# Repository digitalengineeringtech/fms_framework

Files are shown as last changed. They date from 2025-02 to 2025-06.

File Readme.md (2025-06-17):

# FMS Firmware

Fuel Station Monitoring System

## Table of Contents

- [Flow](#flow)
- [VS Code Extension](#vs-code-extension)
- [Compiling Tests](#compiling-tests)
- [Usage/Examples](#usageexamples)
- [Roadmap](#roadmap)
- [Documentation](#documentation)
- [Requirement](#requirement)
- [Skills](#skills)
- [Badges](#badges)

<!-- ## Flow
1. board number
2. crc 
3.  -->
<!-- ![App Screenshot](https://github.com/digitalengineeringtech/fms_framework/blob/main/Flow.jpg) -->

## VS Code Extension

To run this project, you will need to add the following extension variables to your VS Code:

- `Arduino Community Edition`
- `vscode-arduino`

## Compiling Tests

To compile tests, run the following commands:

```bash
ctrl+alt+r   # Compiling sketch
ctrl+alt+u   # Uploading sketch to FMS controller board
```

## Usage/Examples

```c++
#include <fms_header.h>

void setup() {
    fms_log_printf("Program Starting");
    fms_task_create();
}

int strcasecmp(const char *str1, const char *str2);

#include <stdio.h>
#include <strings.h>  // Required for strcasecmp

int main() {
    char str1[] = "Hello";
    char str2[] = "hello";
    
    if (strcasecmp(str1, str2) == 0) {
        printf("Strings are equal (case-insensitive)\n");
    } else {
        printf("Strings are NOT equal\n");
    }
    
    return 0;
}
```

## Roadmap

- All Fuel Protocol Support
- Add more integrations

## Documentation

[Documentation](https://github.com/digitalengineeringtech/fms_framework/blob/main/FMS_FW_Architecture_P2.0.adoc)

## Requirement

[API](https://github.com/digitalengineeringtech/fms_framework/blob/main/whatdo.md)

## Skills

Arduino, FreeRTOS, C++, MQTT, HTML, CSS

## Badges





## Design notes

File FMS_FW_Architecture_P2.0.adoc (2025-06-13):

= Software Architecture for Pump Station with Multiplexer and RS485 Support
:sectnums:
:toc:

[.text-center]
**Company Name**: DET  
[.text-center]
**Engineer Name**: Thiha Kyaw  
[.text-center]
**Document Version**: P2.0  
[.text-center]
**Release Date**: 22-01-2025  

== Version Control Table

[cols="1,3,2,2,3", options="header"]
|===
| Version | Description of Changes | Author | Date | Approval
| P1.0 | Initial version | Thiha Kyaw | 22-01-2025 | Approved by Senior Engineer
| P2.0 | Updated version with multiplexer and RS485 support for pump stations | Thiha Kyaw | 22-01-2025 | Approved by Senior Engineer
| P2.0.1 | Add Cli Command | Nyein Chan Ko | 1-02-2025 | Approved by Senior Engineer
| P2.0.2 | Fix Log Print  | Nyein Chan Ko | 3-03-2025 | Approved by 
| P2.0.3 | Add OTA with Admin | Nyein Chan Ko | 10-03-2025 | Approved by 
| P2.0.4 | Add SD Test | Nyein Chan Ko | 10-03-2025 | Approved by 
| P2.0.5 | Add Modubs Lanfeng | Nyein Chan Ko | 17-03-2025 | Approved by 
| P2.0.6 | Fix Lanfeng Protocol | Nyein Chan Ko | 4-04-2025 | Approved by 
| P2.0.7 | Add Tatsuno | Nyein Chan Ko | 1-06-2025 | Approved by
|===

== Background

This document provides the detailed software architecture for a system designed to acquire data from multiple pumps in a pump station. The system uses an Arduino-based ESP32 microcontroller to communicate with pumps via either RS485 or a hardware multiplexer connected to UART2. Data collected from pumps, such as price, total liters dispensed, and other critical metrics, is transmitted to a remote MQTT server. If the server is unavailable, the data along with error codes are logged into the SDCard and synchronized with the server when communication is restored.

The architecture supports device configuration through a command-line interface (CLI) over UART1 and a user-friendly local web server. Critical device settings, including pump IDs, WiFi credentials, and server configurations, are stored persistently in the SDCard and loaded during device boot-up.

== Requirements

=== Must-Have
1. The system must read data from pumps using UART2 through either RS485 or a hardware multiplexer.
2. The system must provide a CLI for configuration via UART1.
3. The system must host a local web server for device configuration.
4. Configuration settings such as device IDs, WiFi credentials, and pump information must be stored in the SDCard and loaded at boot-up.
5. Data from pumps must be sent to an MQTT server in real time.
6. When the server is unavailable, data and error codes must be logged into the SDCard.
7. Logged data must be synchronized with the server when communication is restored.

=== Should-Have
1. The web server should have password protection for security.
2. The system should support secure MQTT communication (e.g., TLS/SSL).

=== Could-Have
1. The system could store additional logs for detailed troubleshooting.
2. The system could support over-the-air (OTA) firmware updates.

=== Won’t-Have
1. Advanced protocols like Modbus or CAN will not be included in the initial release.
2. High-speed analytics or streaming capabilities will not be implemented on the device.

== Method

=== System Overview
The system is designed with the following key components:
- **Arduino-based Microcontroller**: Manages communication and processing.
- **Hardware Multiplexer** or **RS485**: Allows communication with pumps through UART2.
- **SDCard**: Stores persistent configuration data, logs data when the server is unavailable, and error codes.
- **MQTT Communication**: Sends pump data to the server.
- **Web Server and CLI**: Provide configuration interfaces.

=== Device Configuration Parameters
- **Device ID**: Unique identifier for the device.
- **Station ID**: Identifier for the pump station.
- **WiFi SSID/Password**: WiFi network credentials.
- **MQTT Server IP/Port**: Server details for data transmission.
- **Pump Count/IDs**: Details of connected pumps.
- **Multiplexer Control Pins**: GPIO pin configuration for pump communication (if using Multiplexer).
- **RS485 Configuration**: Communication settings for RS485 (if used).
- **Debug Flags**: Enable/disable debugging.
- **Boot Counter**: Tracks device reboots.

=== Communication Modules
- **UART1 (CLI)**: Used for device configuration via a command-line interface.
- **UART2 (Multiplexer or RS485)**: Used for polling data from pumps via either the multiplexer or RS485, depending on the configuration.

=== MQTT Communication
- Sends pump data to the server in predefined data structure format.
- Ensures reliable delivery through retry mechanisms.

=== SDCard Configuration
- Persistent storage for all configuration settings.
- Logs data and error codes when the server is unavailable.
- Synchronizes logged data back to the server when communication is restored.

=== Web Server
- Hosts a user-friendly HTTP interface.
- Allows users to configure the device securely.

=== Component Diagram
[plantuml, esp32_diagram, png, align="center"]
----
@startuml
node "_ESP32_MCU" {
  component "MCU" as ESP32 #Gold
  component "Web Server" as WebServer
  component "WIFI" as wifi
}

cloud {
  component "Server" as server #LightSkyBlue
}

component "UART1 (CLI)" as UART1 #LightGreen
component "UART2 (RS232)" as UART2 #LightGreen
component "Multiplexer Control" as Multiplexer #LightBlue
component "SDCARD" as SDCARD #LightYellow
component "RS485/RS422" as RS485
component "PUMPs" as Pumps

wifi <.up-> server: "MQTT"
ESP32 <-up-> wifi
wifi <-left-> WebServer
ESP32 --> UART1
ESP32 --> UART2
ESP32 --> SDCARD : SPI
UART2 --> RS485
UART2 -down-> Multiplexer
Multiplexer -down-> Pumps
@enduml
----

=== Firmware Implementation

[plantuml, fw_flowchart, png]
----
@startuml

start

:Initialize ESP32 Hardware;
:Initialize FreeRTOS Scheduler;

:Read Configuration Data from SDCard;
if (Configuration Data Available?) then (Yes)
    :Load Configuration into System;
else (No)
    :Load Default Configuration;
endif

:Create Tasks:
- WiFi Task
- Web Server Task
- UART1 Task
- UART2 Task
- SPI Device Task
- SDCard Task;
:Start FreeRTOS Scheduler;

fork
:WiFi Task;
:Connect to WiFi Network;
:Establish MQTT Connection;
if (MQTT Connected?) then (Yes)
    :Synchronize with Server;
    :Transfer Logged Data from SDCard to Server;
else (No)
    :Log Error: \"Server Unavailable\";
endif
endfork

fork
:SDCard Task;
:Monitor Data to Log;
if (Server Unavailable?) then (Yes)
    :Log Data to SDCard;
    :Store Error Codes to SDCard;
else (No)
    :Sync Data Back to Server;
endif
endfork

fork
:Web Server Task;
:Listen for HTTP Requests;
if (Request for Configuration Data?) then (Yes)
    :Fetch Configuration from SDCard;
    :Send Configuration Data to Client;
else (No)
    :Process Other HTTP Requests;
endif
endfork

fork
:UART1 Task (CLI);
:Monitor Commands from CLI;
if (Configuration Change Command?) then (Yes)
    :Update Configuration in System;
    :Write Updated Configuration to SDCard;
else (No)
    :Route Command to Relevant Subsystem;
endif
endfork

fork
:UART2 Task;
if (Use RS485?) then (Yes)
    :Communicate with RS485 Devices;
else (No - Use Multiplexer)
    :Control PUMPs via Multiplexer;
endif
endfork

fork
:SPI Task;
:Monitor and Process SPI Devices;
:Read Data from SDCard, RFID, RS485;
:Send Data to Server or Log to SDCard;
endfork

while (Monitor Tasks?) is (True)
    if (Error Detected?) then (Yes)
        :Log Error to SDCard;
    else (No)
        :Continue Normal Operations;
    endif
endwhile

stop

@enduml
----
**Key Information**

1. **Configuration Settings:**
- Configuration data is read from the SDCard during the boot-up phase.
- If no configuration is available, default settings are loaded.
2. **Data Logging:**
- When the server is unavailable, logs (data and error codes) are stored on the SDCard.
3. **Data Sync:**
- When communication is restored, logged data is sent back to the server.
4. **CLI Configuration Update:**
- Commands from UART1 can update configuration settings, which are written back to the SDCard.
5. **Error Handling:**
- Errors are logged to the SDCard for debugging and tracking purposes.
6. **Task-Oriented Design:**
- Tasks like WiFi, SDCard, and SPI handle their specific roles independently, ensuring modularity and concurrency.

=== Algorithms
1. **Polling Algorithm**:
   - **Multiplexer Mode**:
     - Iterate over pumps connected via the multiplexer.
     - Select the appropriate pump by controlling GPIO pins.
     - Communicate with the selected pump via UART2 using RS232 commands.
     - Parse the received data and validate the response.
     - Log any errors to the SDCard.
   - **RS485 Mode**:
     - Send RS485 requests to all pumps or targeted devices based on the protocol.
     - Wait for pump responses and parse received data.
     - Log errors for timeouts or protocol violations to the SDCard.

2. **Publishing Algorithm**:
   - Aggregate collected data into a data structure.
   - Publish the data to the MQTT server.
   - If the MQTT server is unavailable, log the data into the SDCard for retry.

3. **Configuration Synchronization**:
   - During boot-up, load configuration from the SDCard.
   - Validate the configuration data for completeness and consistency.
   - Apply configuration to the system and write updates back to the SDCard if modified.

4. **Error Handling**:
   - Log errors, such as communication timeouts or invalid responses, to the SDCard.
   - Attempt retries for failed operations.
   - Notify the server of critical errors via MQTT when connectivity is restored.

5. **Data Recovery**:
   - On server reconnection, retrieve unsent data from the SDCard.
   - Synchronize the logged data with the server to ensure no loss of information.

=== FreeRTOS Task Management
- **WiFi Task**: Manages MQTT connection and reconnection logic.
- **Polling Task**:
  - Operates in either RS485 or multiplexer mode, depending on configuration.
  - Acquires pump data and hands it off for logging or publishing.
- **SDCard Task**: Handles configuration reads/writes and error logging.
- **Web Server Task**: Responds to HTTP requests for configuration changes.
- **CLI Task**: Processes UART1 commands for real-time configuration updates.

== Implementation

=== Step 1: Hardware Setup
1. Connect pumps to the multiplexer inputs.
2. Configure GPIO pins for multiplexer or connect RS485 hardware.
3. Connect the SDCard to the ESP32 via SPI.

=== Step 2: Firmware Development
1. Write code to initialize UART1, UART2, GPIO, and SPI.
2. Implement FreeRTOS tasks for WiFi, SDCard, CLI, and polling.

=== Step 3: Testing and Debugging
1. Verify UART and SPI communication.
2. Test MQTT data publishing and SDCard logging.

=== Step 4: Deployment
1. Flash the firmware onto the ESP32.
2. Deploy the system in a live pump station and monitor performance.

== Milestones

1. **Initial Setup**: Complete hardware connections and communication tests.
2. **Firmware Development**: Implement all modules and FreeRTOS tasks.
3. **MQTT Communication**: Test publishing and error handling.
4. **System Integration**: Combine all components and verify interactions.
5. **Deployment and Testing**: Install the system at a pump station and validate reliability.

== Gathering Results

1. **Functional Testing**: Verify data acquisition and publishing.
2. **Communication Testing**: Validate stability of RS485 and MQTT communication.
3. **Performance Metrics**: Measure response times for data polling and publishing.
4. **Usability Testing**: Evaluate the web interface and CLI for ease of use.
5. **Deployment Validation**: Assess real-world operation and collect stakeholder feedback.

[appendix]
== Additional Information
This appendix contains supplementary information.

=== CLI  commands
Details for Subsection A.1.
[cols="11*", options="header"]
|====================================================================================================================================================================================================================
| No | Description                  | Command   | Value1   | Value2     | Value3     | Value4     | Return Value                                                                   |            | Author | Approve By
| 1  | Device ID                    | devid     | <value>  | -          | -          | -          | value must be : fms%d%time% ...etc                                             |            | NCK    | THK       
| 2  | Version                      | v         | < >      |            | -          | -          | Return Value : FSM V 1.2 ... etc , <Read> mode                                 |            |        | THK       
|    |                              |           |          |            |            |            |                                                                                |            |        | THK       
| 3  | WiFi Scan                    | wifiscan  | -        | -          | -          | -          | Return Value : <ssid1><ssid2><ssid3> ...etc                                    |            |        | THK       
| 4  | WiFi Value                   | wifi      | <ssid>   | <password> |            |            | Return Value : <ok>                                                            |            |        | THK       
|    |                              | wifi      | <read>   | -          | -          | -          | ssid: <ssid>; password: <pass>                                                 |            |        | THK       
|    |                              |           |          |            |            |            |                                                                                |            |        | THK       
| 5  | Mqtt                         | mqtt      | <host>   | <port>     | <username> | <password> | Return Value : <ok>                                                            |            |        | THK       
| 6  |                              | mqtt      | <read>   | -          | -          | -          | <host><port><username><password>                                               |            |        | THK       
| 7  | MqttTopic                    | mqtttopic | <read>   | -          | -          | -          | Return Value : <all topic return> [detpos/route][2][3]... etc                  |            |        | THK       
|    |                              |           |          |            |            |            |                                                                                |            |        | THK       
| 8  | From Sd Card                 | sd        | <read>   | -          | -          | -          | Read All Setting Value Form SD Card and Save to the Flash Storage              |            |        | THK       
| 9  |                              | sd        | <write>  | <all>      | -          | -          | Write All Setting Value to SD Card                                             |            |        | THK       
|    |                              |           |          |            |            |            |                                                                                |            |        | THK       
| 10 | Fuel Nozzel Count            | nozc      | <value>  |            |            |            | value : 1,2,3,4,6 ...etc                                                       |            |        | THK       
| 11 | Fuel Nozzel ID               | nozid     | <value1> | <value2>   | <value3>   | <value4>   | <nozzel id change done> id:1,2,3,4,5 ... etc                                   |            |        | THK       
|    |                              |           |          |            |            |            |                                                                                |            |        | THK       
| 12 | Fuel Station ID              | statid    | <value>  | -          | -          | -          | value: 01,02,03,04,05 ... etc                                                  |            |        | THK       
|    |                              |           |          |            |            |            |                                                                                |            |        | THK       
| 13 | Show All CMD                 | help      | -        | -          | -          | -          | Show All Command List read mode                                                |            |        | THK       
| 14 | Show All log                 | syslog    | <read>   | -          | -          | -          | Return Value : <bootcount><mqttreconnectcount><errostate>... etc               |            |        | THK       
| 15 | log download File to Sd Card | syslog    | <write>  | -          | -          | -          | download & generate log file to sd, log%time%.txt                              |            |        | THK       
| 16 | Select download type         | fstype    | <value>  | -          | -          | -          | Select File System Type 0: Flash Storage, 1: SD card, Default : 1 : SD card    | Optional   |        | THK       
|    | Debug mode                   |           |          |            |            |            | enable printf to UART1                                                         |            |        | THK       
|    | Protocol Settings            |           |          |            |            |            | Which pump                                                                     |            |        | THK       
|    |                              |           |          |            |            |            |                                                                                |            |        |           
| 17 | Read All Setting Value       | sys       | <read>   | -          | -          | -          | Return Value : Type : Json Format {"ssid";" " ,"password : " ","host": " "...} | For PyQTui |        |           
|====================================================================================================================================================================================================================

[appendix]
== Pump Protocols
=== Lanfeng Protocols

    - Using Modbus Communication , Controll Pump, Preset Amount, Price,
    to fill
Details for Subsection B.1.

    Lanfeng Protocols , modbus protocol 

=== Tatsuno Protocols

    - Using Modbus Communication , Controll Pump, Preset Amount, Price,
    to fill

=== RedStar Protocols

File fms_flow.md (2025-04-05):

```plantuml
@startuml
skin rose
start
:Initialize ESP32 Hardware;
note left
ESP32 HARDWARE  DONE
end note
: WiFi;
if (WiFi Connected?) then (Yes)
    :Start Normal Operation;
else (No)
    : Show Fail connection;
    : Check WiFi Ssid & Pass;

endif

:Initialize FreeRTOS Scheduler;

:Read Configuration Data from SDCard;
if (Configuration Data Available?) then (Yes)
    :Load Configuration into System;
else (No)
    :Load Default Configuration;
endif

:Create Tasks:
- WiFi Task
- Web Server Task
- UART1 Task
- UART2 Task
- SPI Device Task
- SDCard Task;
:Start FreeRTOS Scheduler;

fork
:WiFi Task;
:Connect to WiFi Network;
:Establish MQTT Connection;
if (MQTT Connected?) then (Yes)
    :Synchronize with Server;
    :Get permit message from server;
    :Transfer Logged Data from SDCard to Server;
else (No)
    :Log Error: \"Server Unavailable\";
endif
endfork

fork
:SDCard Task;
:Monitor Data to Log;
if (Server Unavailable?) then (Yes)
    :Log Data to SDCard;
    :Store Error Codes to SDCard;
else (No)
    :Sync Data Back to Server;
endif
endfork

fork
:Web Server Task;
:Listen for HTTP Requests;
if (Request for Configuration Data?) then (Yes)
    :Fetch Configuration from SDCard;
    :Send Configuration Data to Client;
else (No)
    :Process Other HTTP Requests;
endif
endfork

fork
:UART1 Task (CLI);
:Monitor Commands from CLI;
if (Configuration Change Command?) then (Yes)
    :Update Configuration in System;
    :Write Updated Configuration to SDCard;
else (No)
    :Route Command to Relevant Subsystem;
endif
endfork

fork
:UART2 Task;
if (Use RS485?) then (Yes)
    :Communicate with RS485 Devices;
else (No - Use Multiplexer)
    :Control PUMPs via Multiplexer;
endif
endfork

fork
:SPI Task;
:Monitor and Process SPI Devices;
:Read Data from SDCard, RFID, RS485;
:Send Data to Server or Log to SDCard;
endfork

while (Monitor Tasks?) is (True)
    if (Error Detected?) then (Yes)
        :Log Error to SDCard;
    else (No)
        :Continue Normal Operations;
    endif
endwhile

stop

@enduml

```

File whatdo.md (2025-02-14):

# 🚀 ESP32 Memory Optimization Guide

Optimizing memory usage on the ESP32 ensures **efficient performance**, prevents **crashes**, and extends **device reliability**. Below are key strategies for **heap**, **stack**, and **GPIO** memory optimization.

---

## 🟢 1. Optimize Stack Memory (Avoid Overflows)
### ✅ Reduce Large Local Variables
- Large local variables take up **stack space**, increasing overflow risks.
- **Solution:** Move large variables to the **heap** instead.

**🔴 Bad (Stack Usage - Risky!)**
```cpp
void function() {
    char buffer[4096];  // Too big! Might cause stack overflow.
}
```
**🟢 Good (Heap Usage - Safer)**
```cpp
void function() {
    char *buffer = (char*) malloc(4096);
    if (buffer) {
        // Use buffer...
        free(buffer);
    }
}
```

### ✅ Increase Stack Size for Tasks (FreeRTOS)
If your **task crashes** due to stack overflow, increase its stack size in **xTaskCreate()**:
```cpp
xTaskCreatePinnedToCore(myTask, "MyTask", 4096, NULL, 1, NULL, 0);
```
📌 **Tip:** Use `uxTaskGetStackHighWaterMark(NULL);` to check **remaining stack space**.

---

## 🟢 2. Optimize Heap Memory (Prevent Leaks & Fragmentation)
### ✅ Use Heap Only When Necessary
Heap allocations (`malloc()`, `new`) consume memory **dynamically**. Unused allocations cause **memory leaks**.

**🔴 Bad (Heap Leaks - Never Freed!)**
```cpp
void allocateMemory() {
    int *arr = (int*) malloc(100 * sizeof(int));
    arr[0] = 42;  // Memory is never freed!
}
```
**🟢 Good (Proper Cleanup)**
```cpp
void allocateMemory() {
    int *arr = (int*) malloc(100 * sizeof(int));
    if (arr) {
        arr[0] = 42;
        free(arr);  // Free memory to avoid leaks!
    }
}
```
📌 **Tip:** Use `esp_get_free_heap_size();` to check available heap.

### ✅ Use PSRAM (External RAM) for Large Buffers
If your ESP32 has **PSRAM (ESP32-WROVER, ESP32-S3)**, use it for large allocations:
```cpp
#include "esp_heap_caps.h"
uint8_t *bigBuffer = (uint8_t*) heap_caps_malloc(50000, MALLOC_CAP_SPIRAM);
```
📌 **Tip:** Use PSRAM for **camera buffers, large arrays, and AI models**.

---

## 🟢 3. Optimize Flash Storage (Reduce NVS Usage)
### ✅ Minimize NVS (Non-Volatile Storage) Writes
Frequent NVS writes **wear out** flash memory. Store only necessary settings.
```cpp
#include <Preferences.h>
Preferences prefs;

void setup() {
    prefs.begin("my_app", false);  // Open NVS
    prefs.putInt("boot_count", prefs.getInt("boot_count", 0) + 1);
    prefs.end();  // Close to save space!
}
```
📌 **Tip:** Use `nvs_get_stats()` to monitor NVS usage.

---

## 🟢 4. Reduce String Usage (Avoid Dynamic `String` Objects)
ESP32’s `String` class causes **heap fragmentation** due to unpredictable resizing.

**🔴 Bad (`String` Causes Fragmentation)**
```cpp
String message = "Hello";
message += " World";  // Memory allocation every time it's modified!
```
**🟢 Good (Use Character Arrays)**
```cpp
char message[20] = "Hello";
strcat(message, " World");
```

---

## 🟢 5. Optimize GPIO Usage (Efficient Digital Output)
### ✅ Use `gpio_set_level()` Efficiently
Instead of using `digitalWrite()`, use `gpio_set_level()` for **faster** and **optimized** GPIO control:
```cpp
#include "driver/gpio.h"
#define LED_PIN GPIO_NUM_2

void setup() {
    gpio_pad_select_gpio(LED_PIN);
    gpio_set_direction(LED_PIN, GPIO_MODE_OUTPUT);
}

void loop() {
    gpio_set_level(LED_PIN, 1); // Turn LED ON
    delay(500);
    gpio_set_level(LED_PIN, 0); // Turn LED OFF
    delay(500);
}
```
📌 **Tip:** `gpio_set_level()` is significantly faster than `digitalWrite()` on ESP32.

---

## 🟢 6. Monitor and Debug Memory Usage
### ✅ Check Heap and Stack Usage in Runtime
```cpp
void checkMemory() {
    Serial.printf("Free Heap: %d bytes\n", esp_get_free_heap_size());
    Serial.printf("Task Stack High Water: %d bytes\n", uxTaskGetStackHighWaterMark(NULL));
}
```

### ✅ Use ESP-IDF Memory Debugging Tools
Enable **heap debugging** in PlatformIO or ESP-IDF:
```cpp
heap_caps_print_heap_info(MALLOC_CAP_INTERNAL);
```

---

## 🔥 Final Summary: Key Optimization Techniques

| Problem 🚨 | Solution ✅ |
|---|---|
| Stack Overflow | Reduce local variable size, increase stack size |
| Memory Leaks | Always free `malloc()` allocations |
| Heap Fragmentation | Avoid `String`, use fixed-size char arrays |
| Flash Wear | Minimize NVS writes |
| Large Data Buffers | Use PSRAM on ESP32-WROVER |
| Slow GPIO Performance | Use `gpio_set_level()` instead of `digitalWrite()` |

---

# PubSubClient API Documentation

## 1. Include the Library

To use the **PubSubClient** library in your Arduino sketch, include the library as shown below:

```cpp
#include <PubSubClient.h>
```

## 2. Initializing the Client

The `PubSubClient` object can be initialized using the Ethernet or WiFi client as a transport layer:

### For WiFi:

```cpp
WiFiClient espClient;
PubSubClient client(espClient);
```

### For Ethernet:

```cpp
EthernetClient ethClient;
PubSubClient client(ethClient);
```

## 3. MQTT Connection Functions

- **setServer**: Set the broker's IP address (or hostname) and port.

```cpp
client.setServer("mqtt.example.com", 1883);
```

- **setCallback**: Set the callback function to handle incoming messages from the broker.

```cpp
client.setCallback(callback);
```

The callback function is defined like this:

```cpp
void callback(char* topic, byte* payload, unsigned int length) {
  // Handle message here
}
```

- **connect**: Connect to the MQTT broker with optional username and password.

```cpp
if (client.connect("client_id", "username", "password")) {
  // Successfully connected
}
```

- **connect with Last Will and Testament (LWT)**: Set a Last Will message when connecting to the broker.

```cpp
client.connect("client_id", "username", "password", "lwt_topic", 1, true, "LWT Message");
```

## 4. Publishing Messages

- **publish**: Publish a message to a topic.

```cpp
client.publish("topic", "message");
```

You can also publish messages with QoS (Quality of Service) level and retain flags:

- **QoS 1** (Message is guaranteed to be delivered at least once):

```cpp
client.publish("topic", "message", true, 1);
```

- **Retain flag**: If `true`, the broker will retain the message:

```cpp
client.publish("topic", "message", true, 0);
```

## 5. Subscribing to Topics

- **subscribe**: Subscribe to one or more topics.

```cpp
client.subscribe("topic");
```

- **subscribe with QoS**: Subscribe to a topic with a specified QoS level:

```cpp
client.subscribe("topic", 1);
```

- **unsubscribe**: Unsubscribe from a topic.

```cpp
client.unsubscribe("topic");
```

## 6. Loop and Connection Management

- **loop**: This function must be called repeatedly to maintain the connection to the MQTT broker and process incoming messages.

```cpp
client.loop();
```

- **connected**: Check if the client is connected to the broker.

```cpp
if (client.connected()) {
  // The client is connected
}
```

- **disconnect**: Disconnect the client from the broker.

```cpp
client.disconnect();
```

## 7. Additional Configuration Methods

- **setKeepAlive**: Set the keep-alive period (in seconds). The client will send a ping request to the broker if no other message is sent within this time.

```cpp
client.setKeepAlive(60); // 60 seconds
```

- **setBufferSize**: Set the buffer size for incoming messages.

```cpp
client.setBufferSize(1024); // 1024 bytes
```

- **setReconnecting**: Configure the automatic reconnection behavior.

```cpp
client.setReconnecting(true);
```

## 8. Last Will and Testament (LWT)

Set a last will message that is sent to a specific topic if the client unexpectedly disconnects:

```cpp
client.setWill("home/temperature", 0, true, "Offline");
```

## 9. Example Sketch

Here is an example of using **PubSubClient** with an ESP8266 or ESP32 to connect to an MQTT broker, subscribe to a topic, and handle incoming messages:

```cpp
#include <ESP8266WiFi.h>
#include <PubSubClient.h>

// WiFi credentials
const char* ssid = "yourSSID";
const char* password = "yourPassword";

// MQTT broker settings
const char* mqtt_server = "mqtt.example.com";
WiFiClient espClient;
PubSubClient client(espClient);

void setup() {
  Serial.begin(115200);
  
  // Connect to WiFi
  setup_wifi();

  // Set MQTT server and callback function
  client.setServer(mqtt_server, 1883);
  client.setCallback(callback);
  
  // Connect to MQTT broker
  while (!client.connected()) {
    if (client.connect("ESP8266Client")) {
      Serial.println("Connected to MQTT broker!");
      client.subscribe("home/temperature");
    } else {
      delay(5000);
    }
  }
}

void loop() {
  client.loop(); // Keep the connection alive
}

void setup_wifi() {
  delay(10);
  Serial.println();
  Serial.print("Connecting to WiFi...");
  
  WiFi.begin(ssid, password);
  
  while (WiFi.status() != WL_CONNECTED) {
    delay(250);
    Serial.print(".");
  }
  
  Serial.println("Connected!");
  Serial.println("IP address: " + WiFi.localIP().toString());
}

void callback(char* topic, byte* payload, unsigned int length) {
  Serial.print("Message arrived [");
  Serial.print(topic);
  Serial.print("] ");
  
  for (int i = 0; i < length; i++) {
    Serial.print((char)payload[i]);
  }
  
  Serial.println();
}
```

## 10. Summary of Key PubSubClient Methods

- **client.setServer**: Set the broker address and port.
- **client.setCallback**: Set the callback function for incoming messages.
- **client.connect**: Connect to the MQTT broker.
- **client.publish**: Publish a message to a topic.
- **client.subscribe**: Subscribe to a topic.
- **client.unsubscribe**: Unsubscribe from a topic.
- **client.loop**: Keep the MQTT connection alive and handle messages.
- **client.disconnect**: Disconnect from the broker.
- **client.setWill**: Set the Last Will and Testament (LWT).
```

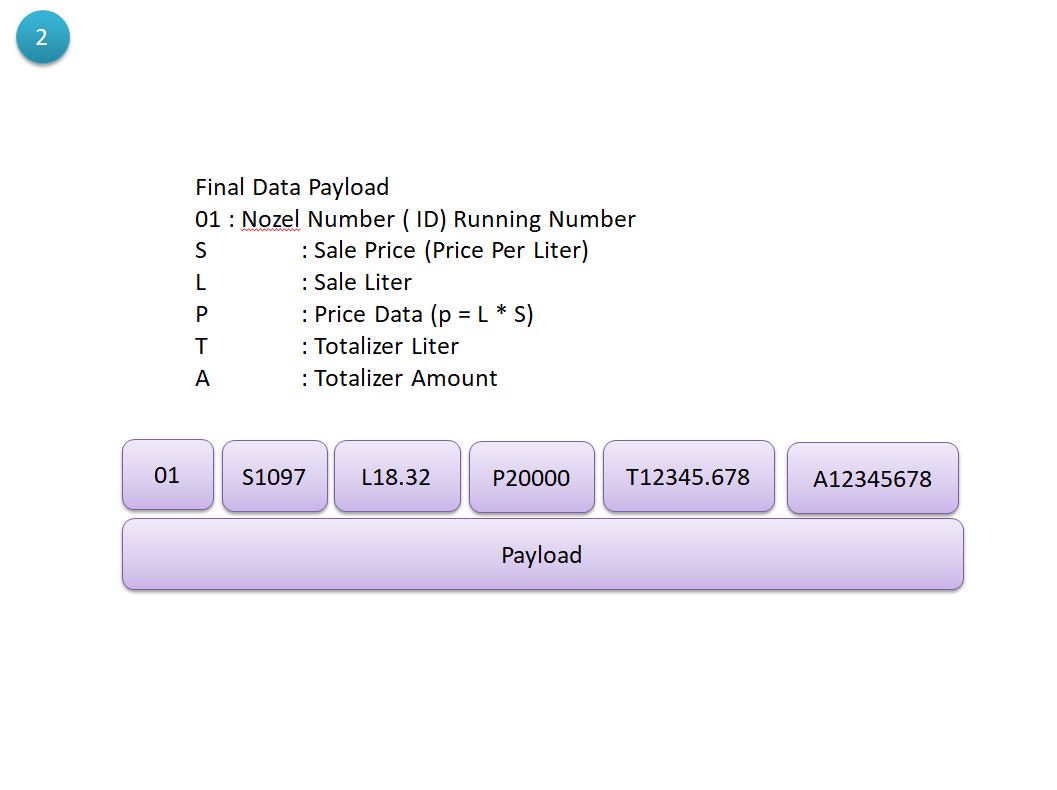
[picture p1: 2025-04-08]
frame_format_2.JPG

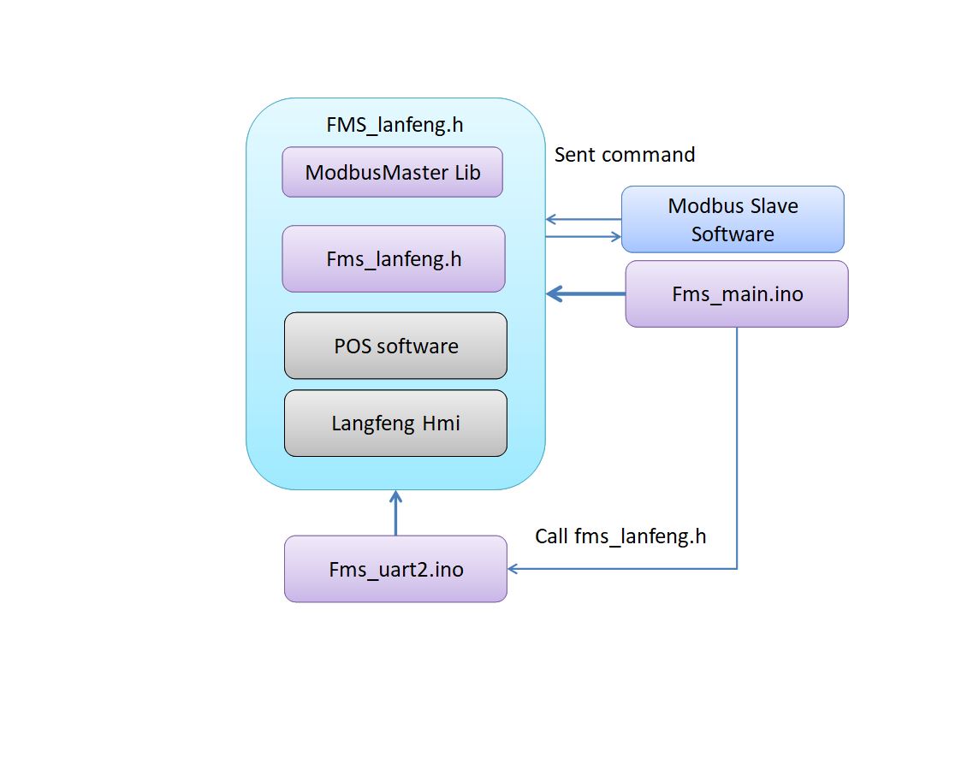
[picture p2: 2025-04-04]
Flow.jpg

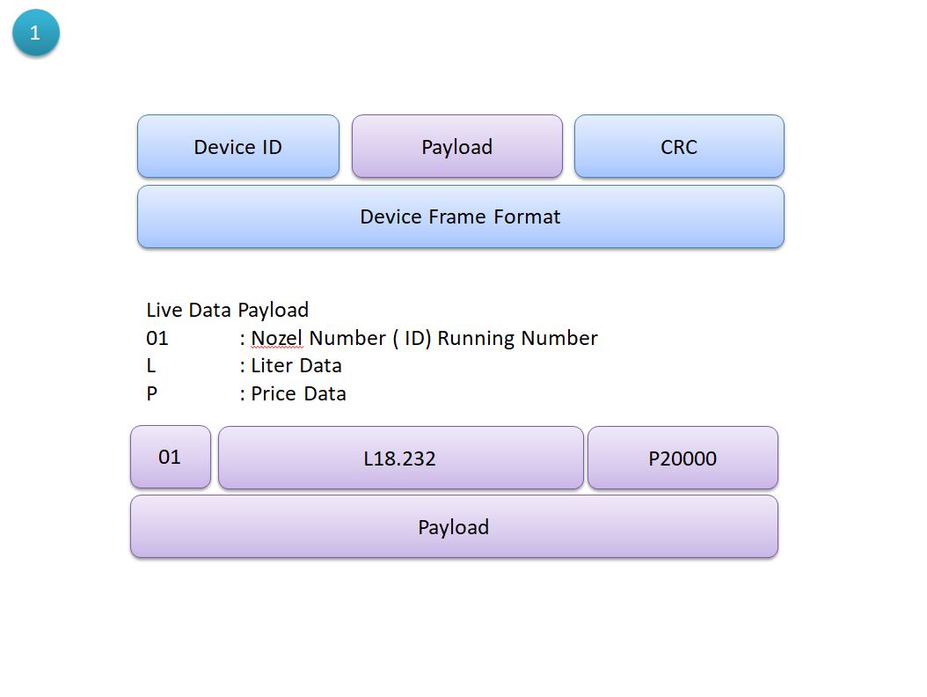
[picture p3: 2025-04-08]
frame_format.JPG

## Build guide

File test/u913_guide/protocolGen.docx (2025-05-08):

Redstar

If reply data is 0x12, 0x57

This the final data, user get

Send fuel function, send read price, and send read total and then MQTT final response

Please note to pump status = fuel

If reply data is 0x12, 0x77

This the pump approve sending

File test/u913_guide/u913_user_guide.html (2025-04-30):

# ESP32 Fuel Dispenser Control System

User Guide and Documentation

## Table of Contents

- 1. Introduction
- 2. Hardware Requirements
- 3. Installation
  - 3.1 Hardware Setup
  - 3.2 Software Setup
- 4. Usage
  - 4.1 Web Interface
  - 4.2 Available Commands
- 5. Communication Protocol
  - 5.1 Protocol Overview
  - 5.2 Parity Switching Technique
  - 5.3 Command Format
  - 5.4 Response Format
- 6. Troubleshooting
- 7. Advanced Tools
  - 7.1 Protocol Analyzer
- 8. Appendix

## 1. Introduction

The ESP32 Fuel Dispenser Control System is a modern replacement for traditional control systems, allowing you to manage fuel dispensers using an ESP32 microcontroller. This system provides both a web interface and serial communication capabilities to control various aspects of fuel dispensers.

This system is a direct replacement for the legacy Visual Basic application, offering the same functionality but with modern hardware and improved connectivity options.

### Key Features

- Price change functionality
- Reading and clearing shift totals
- Stopping pumps
- Requesting real-time amount and volume data
- Web-based interface accessible from any device
- WiFi connectivity
- Serial communication with fuel dispensers
- Protocol analyzer for debugging

## 2. Hardware Requirements

To set up the ESP32 Fuel Dispenser Control System, you will need the following components:

Component | Description | Purpose
ESP32 Development Board | Any ESP32-based board (e.g., ESP32 DevKit, NodeMCU-32S) | Main controller
RS232 to TTL Converter | MAX3232 or similar converter | Interface between ESP32 and fuel dispenser
Power Supply | 5V DC power supply | Power for the ESP32
Connecting Wires | Jumper wires, connectors | Connections between components
Optional: Display | OLED or LCD display | Local status display
Optional: Buttons | Push buttons | Physical control interface

Note: The ESP32 must be connected to a WiFi network for the web interface to be accessible.

## 3. Installation

### 3.1 Hardware Setup

Follow these steps to set up the hardware components:

1. Connect the RS232 to TTL converter to the ESP32:
  - Connect the TX pin of the ESP32 (GPIO17) to the RX pin of the converter
  - Connect the RX pin of the ESP32 (GPIO16) to the TX pin of the converter
  - Connect GND of the ESP32 to GND of the converter
  - Connect VCC of the converter to 3.3V of the ESP32
2. Connect the RS232 side of the converter to the fuel dispenser:
  - Use a standard DB9 connector to connect to the fuel dispenser
  - Ensure proper pinout according to the fuel dispenser's specifications
3. Power the ESP32:
  - Connect the ESP32 to a 5V power supply via USB or external power input

Warning: Always ensure that all connections are correct before powering on the system. Incorrect wiring may damage the components.

#### Wiring Diagram

ESP32           RS232-TTL Converter           Fuel Dispenser
------          -----------------             --------------
GPIO17 (TX) --> RX                            
GPIO16 (RX) <-- TX                            
3.3V        --> VCC                           
GND         --> GND                           
                RS232 TX        ------------> RX
                RS232 RX        <------------ TX
                RS232 GND       <-----------> GND

### 3.2 Software Setup

Follow these steps to set up the software:

1. Install the Arduino IDE:
  - Download and install the Arduino IDE from arduino.cc (https://www.arduino.cc/en/software)
  - Install the ESP32 board package in the Arduino IDE
2. Install Required Libraries:
  - Open the Arduino IDE
  - Go to Sketch > Include Library > Manage Libraries
  - Search for and install the following libraries:
    - ArduinoJson
    - CircularBuffer (for the Protocol Analyzer)
3. Configure the Code:
  - Open the provided Arduino sketch
  - Modify the WiFi credentials:

const char* ssid = "YourWiFiSSID";
const char* password = "YourWiFiPassword";
  - Adjust the serial pins if necessary:

#define DISPENSER_RX_PIN 16  // GPIO16 for RX
#define DISPENSER_TX_PIN 17  // GPIO17 for TX

4. Upload the Code:
  - Connect the ESP32 to your computer via USB
  - Select the correct board and port in the Arduino IDE
  - Click the Upload button
5. Verify Installation:
  - Open the Serial Monitor in the Arduino IDE (115200 baud)
  - Check for the "Connected to WiFi" message and note the IP address

Note: The ESP32 will automatically connect to the configured WiFi network on startup. If the connection fails, the system will continue to retry.

## 4. Usage

### 4.1 Web Interface

The system provides a web interface that can be accessed from any device on the same network as the ESP32.

#### Accessing the Web Interface

1. Connect your device (computer, tablet, smartphone) to the same WiFi network as the ESP32
2. Open a web browser
3. Enter the IP address of the ESP32 in the address bar (e.g., 192.168.1.100)
4. The web interface should load, showing the control panel

#### Web Interface Features

- Nozzle ID Setting: Set the ID of the nozzle/pump you want to control
- COM Port Setting: Set the COM port number (maintained for compatibility)
- Command Buttons: Buttons for each available command
- Price Data Input: Input field for price data (used for price change command)
- Response Display: Area showing the command sent and response received from the dispenser

Note: The web interface automatically updates the response area when new data is received from the fuel dispenser.

### 4.2 Available Commands

The system supports the following commands for controlling the fuel dispenser:

Command | Description | Parameters | Response
Price Change | Changes the price setting on the fuel dispenser | Price value (numeric) | 3 bytes confirmation
Clear Shift Total | Clears the shift total counters | None | 3 bytes confirmation
Read Shift Total | Reads the current shift total values | None | 15 bytes with total data
Stop Pump | Stops the pump operation immediately | None | 3 bytes confirmation
Request Real-time Data | Requests current amount and volume data | None | 13 bytes with real-time data

#### Using Commands

1. Set the Nozzle ID to match the target fuel dispenser
2. For Price Change command, enter the price value in the Price Data field
3. Click the desired command button
4. The system will send the command and display the response in the Response area

## 5. Communication Protocol

### 5.1 Protocol Overview

The system communicates with fuel dispensers using a specific protocol over serial connection. Understanding this protocol is essential for troubleshooting and advanced usage.

#### Basic Protocol Specifications

- Baud Rate: 2400 bps
- Data Bits: 8
- Parity: Varies (Mark for address, Space for data)
- Stop Bits: 1

### 5.2 Parity Switching Technique

A key aspect of this protocol is the use of different parity settings for different parts of the communication:

- Mark Parity (m): Used when sending the initial address byte
  - Settings: "2400,m,8,1"
  - Parity bit is always set to 1
  - This signals to the dispenser that the byte is an address
- Space Parity (s): Used when sending the command data
  - Settings: "2400,s,8,1"
  - Parity bit is always set to 0
  - This signals to the dispenser that these bytes are command data

This parity switching technique is a protocol-specific way to differentiate between address bytes and data bytes without requiring additional framing or control bytes.

Note: The ESP32 implementation handles this parity switching automatically when sending commands.

### 5.3 Command Format

Each command follows this general structure:

1. Send the nozzle address byte with MARK parity
2. Send the command packet with SPACE parity:
  - First byte: Length of the command (including length byte)
  - Second byte: Command code
  - Additional bytes: Command parameters (if any)
  - Last byte: Checksum

#### Checksum Calculation

The checksum is calculated as follows:

checksum = (0x10000 - (address + all command bytes)) & 0xFF

#### Command Examples

Price Change Command (Address = 1, Price = 1234)

Address byte (Mark parity): 01

Command bytes (Space parity): 07 80 00 00 04 D2 A2

- 07: Length (7 bytes)
- 80: Command code for price change
- 00 00 04 D2: Price value (1234 in hex)
- A2: Checksum

Read Shift Total Command (Address = 1)

Address byte (Mark parity): 01

Command bytes (Space parity): 03 8D 6F

- 03: Length (3 bytes)
- 8D: Command code for read shift total
- 6F: Checksum

Stop Pump Command (Address = 1)

Address byte (Mark parity): 01

Command bytes (Space parity): 03 10 EC

- 03: Length (3 bytes)
- 10: Command code for stop pump
- EC: Checksum

### 5.4 Response Format

The fuel dispenser responds to commands with different formats depending on the command type:

#### Standard Acknowledgement (3 bytes)

- First byte: Status code (0x00 = success)
- Second byte: Echo of the command code
- Third byte: Checksum

#### Shift Total Response (15 bytes)

- First byte: Status code
- Second byte: Echo of the command code (0x8D)
- Third byte: Data length
- Bytes 4-7: Volume data (4 bytes)
- Bytes 8-11: Amount data (4 bytes)
- Bytes 12-13: Transaction count (2 bytes)
- Bytes 14-15: Reserved

#### Real-time Data Response (13 bytes)

- First byte: Status code
- Second byte: Echo of the command code (0x8F)
- Third byte: Data length
- Bytes 4-7: Volume data (4 bytes)
- Bytes 8-11: Amount data (4 bytes)
- Byte 12: Pump status
- Byte 13: Checksum

Note: All multi-byte values are in big-endian format (most significant byte first).

## 6. Troubleshooting

If you encounter issues with the system, try these troubleshooting steps:

### Common Issues and Solutions

#### System Not Connecting to WiFi

- Check that the WiFi credentials are correct in the code
- Ensure the WiFi network is operational
- Verify the ESP32 is within range of the WiFi router
- Try rebooting the ESP32

#### No Response from Fuel Dispenser

- Verify the wiring connections between ESP32, converter, and dispenser
- Check that the correct nozzle ID is being used
- Ensure the baud rate and parity settings are correct
- Check if the dispenser is powered on and operational
- Try a different RS232 to TTL converter
- Use the Protocol Analyzer to debug the communication

#### Incorrect Parity Settings

- Ensure the code is correctly switching between Mark and Space parity
- Verify that the ESP32 hardware supports parity switching
- Try using the Protocol Analyzer to manually test different parity settings

#### Web Interface Not Loading

- Verify you're using the correct IP address
- Ensure your device is on the same network as the ESP32
- Try accessing the interface from a different device or browser
- Restart the ESP32

#### Commands Not Working

- Check the serial monitor for error messages
- Verify the command format is correct
- Ensure the dispenser is in a state where it can accept the command
- Try a simpler command first (like Read Shift Total) to test communication

Warning: If you're experiencing persistent issues with the fuel dispenser, consult the dispenser's manual or contact the manufacturer for support.

## 7. Advanced Tools

### 7.1 Protocol Analyzer

The system includes a Protocol Analyzer tool that helps debug communication issues with the fuel dispenser. This tool allows you to:

- Monitor all serial communication in real-time
- Manually switch between Mark and Space parity
- Send custom hex commands to the dispenser
- View detailed logs of all communication

#### Using the Protocol Analyzer

1. Upload the protocol-analyzer.ino sketch to your ESP32
2. Connect to the ESP32's web interface
3. Use the control panel to:
  - Start/stop monitoring
  - Switch parity settings
  - Send custom hex data
  - View the communication log

#### Interpreting the Logs

The Protocol Analyzer logs show all communication with timestamps:

- TX: Data transmitted from ESP32 to dispenser
- RX: Data received from dispenser to ESP32
- System: System messages and status updates
- Error: Error messages and warnings

Note: The Protocol Analyzer is an advanced tool intended for debugging and development. It requires understanding of the fuel dispenser protocol.

## 8. Appendix

### Command Reference

#### Price Change Command (0x80)

Format: [Address] [0x07] [0x80] [Price Byte 3] [Price Byte 2] [Price Byte 1] [Price Byte 0] [Checksum]

Example (Price = 1234, Address = 1):

01 07 80 00 00 04 D2 A2

#### Clear Shift Total Command (0x04)

Format: [Address] [0x03] [0x04] [Checksum]

Example (Address = 1):

01 03 04 F8

#### Read Shift Total Command (0x8D)

Format: [Address] [0x03] [0x8D] [Checksum]

Example (Address = 1):

01 03 8D 6F

#### Stop Pump Command (0x10)

Format: [Address] [0x03] [0x10] [Checksum]

Example (Address = 1):

01 03 10 EC

#### Request Real-time Data Command (0x8F)

Format: [Address] [0x03] [0x8F] [Checksum]

Example (Address = 1):

01 03 8F 6D

### Response Formats

#### Standard Acknowledgement (3 bytes)

Format: [Status] [Command Echo] [Checksum]

#### Shift Total Response (15 bytes)

Format: [Status] [Command Echo] [Data Length] [Volume Bytes (4)] [Amount Bytes (4)] [Transaction Count (2)] [Reserved (2)] [Checksum]

#### Real-time Data Response (13 bytes)

Format: [Status] [Command Echo] [Data Length] [Volume Bytes (4)] [Amount Bytes (4)] [Status Byte] [Checksum]

### Status Codes

Code | Description
0x00 | Success
0x01 | Error - Invalid Command
0x02 | Error - Invalid Parameter
0x03 | Error - Device Busy
0x04 | Error - Operation Failed

### Pump Status Codes

Code | Description
0x00 | Idle
0x01 | Authorized
0x02 | Fueling
0x03 | Fueling Complete
0x04 | Suspended

© 2025 ESP32 Fuel Dispenser Control System

Version 1.0

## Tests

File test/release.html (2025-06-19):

## Release binaries for ultm firmware on ESP32

Firmware for ESP32 with easy configuration using webUI, OTA updates, over MQTT, HTTP, Serial.

Find latest development binaries for ultramarine firmware at http://ota.ultm/firmware (https://github.com/digitalengineeringtech/fms_framework/releases/tag/v2.0.0).

These binaries are built using core 3.1.3 and idf 5.3.3

### English language feature versions

OTA Firmware | OTA URL | Size | Timestamp
ultm_fw_v2.bin (https://github.com/digitalengineeringtech/fms_framework/releases/download/v2.0.0/ultm_fw_v2.0.bin) | https://github.com/digitalengineeringtech/fms_framework/releases/download/v2.0.0/ultm_fw_v2.0.bin | 1 MB | 17062025 12:00

ultm_fwv2.0 by iih (https://github.com/digitalengineeringtech/fms_framework)

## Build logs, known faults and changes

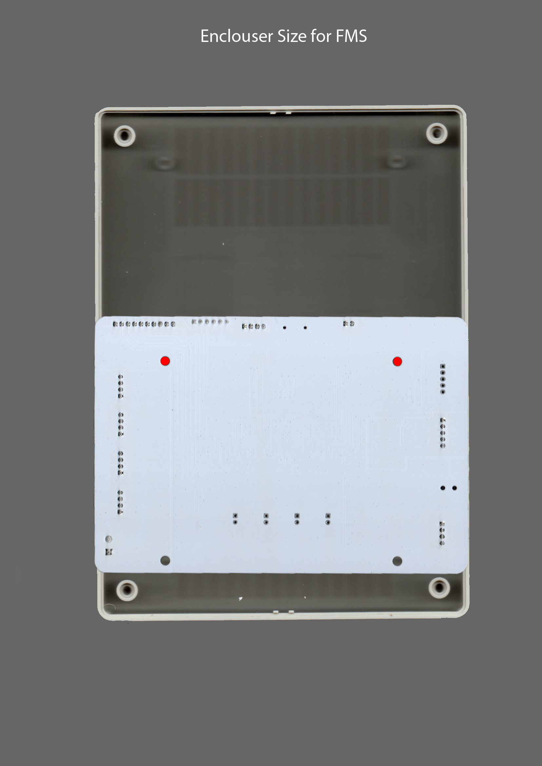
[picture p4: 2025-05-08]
test/fix_design/sizeofBoard copy.png

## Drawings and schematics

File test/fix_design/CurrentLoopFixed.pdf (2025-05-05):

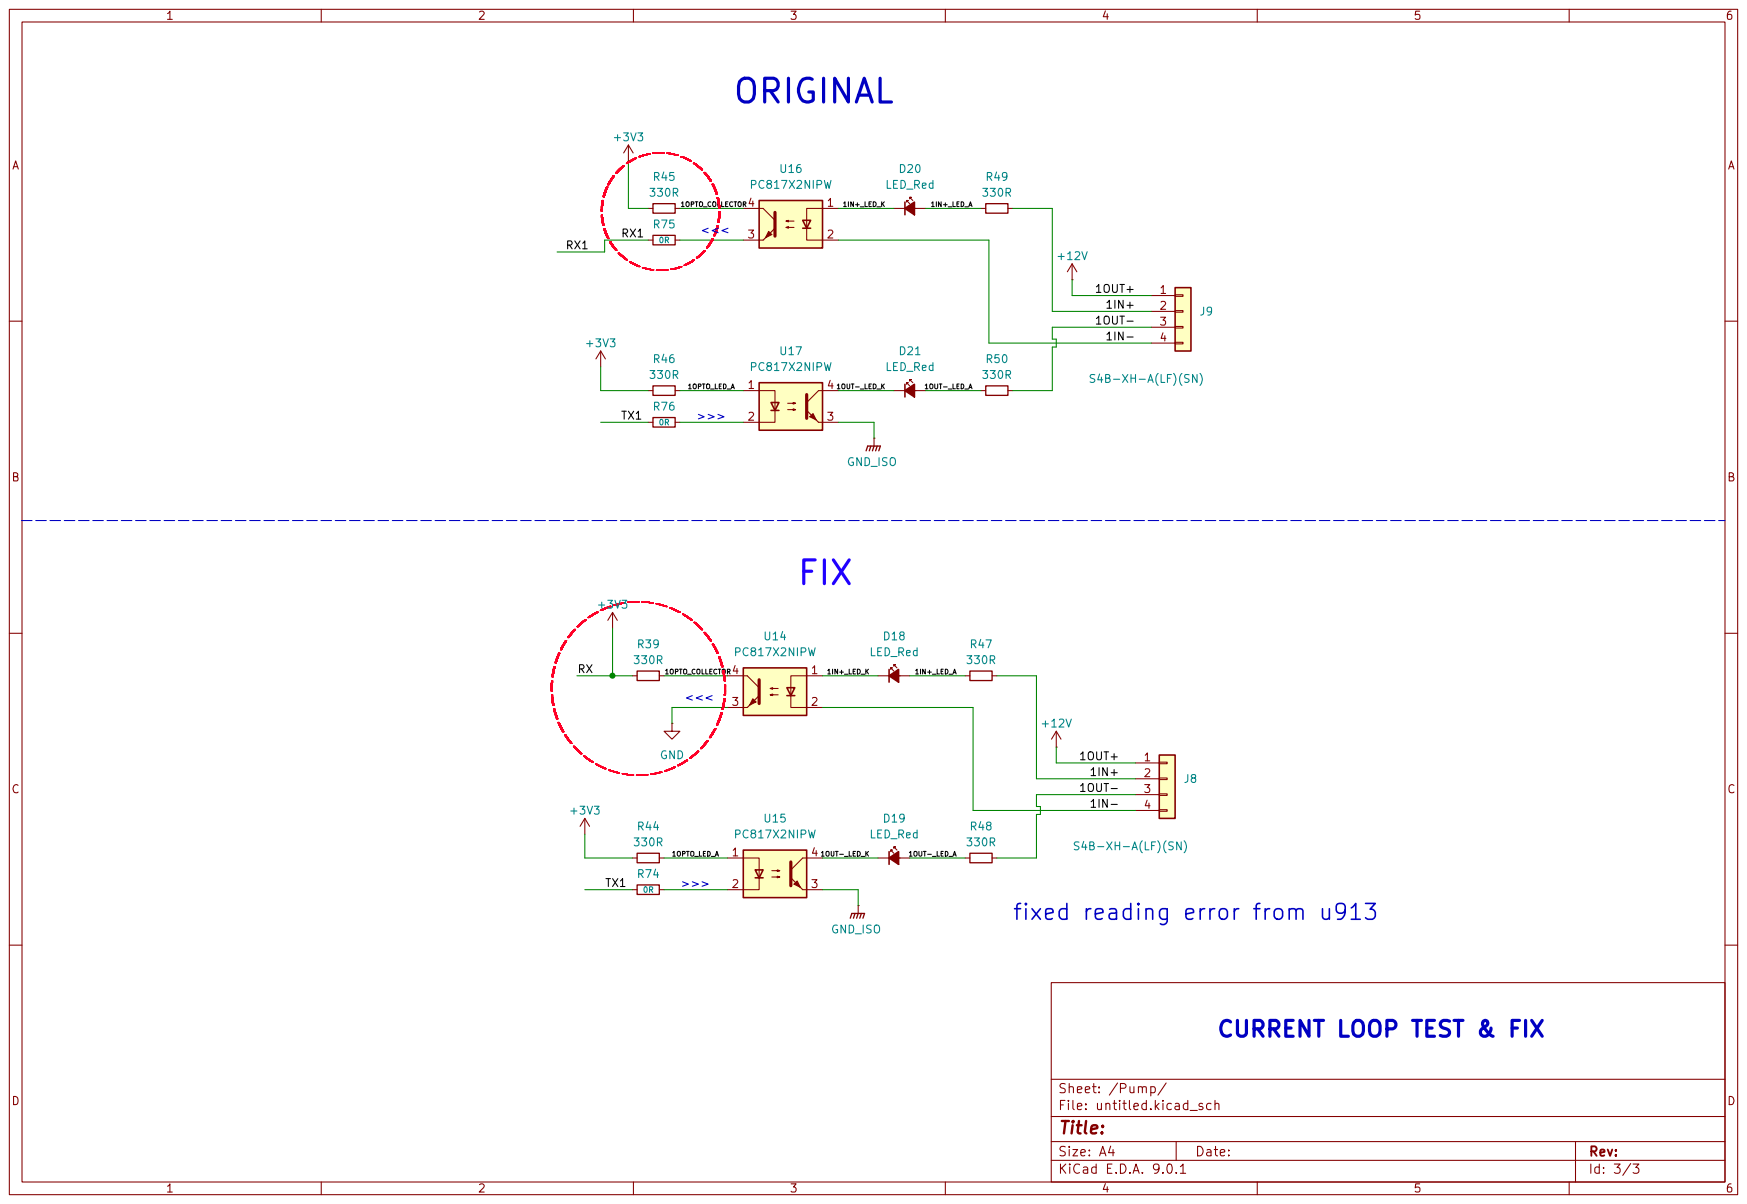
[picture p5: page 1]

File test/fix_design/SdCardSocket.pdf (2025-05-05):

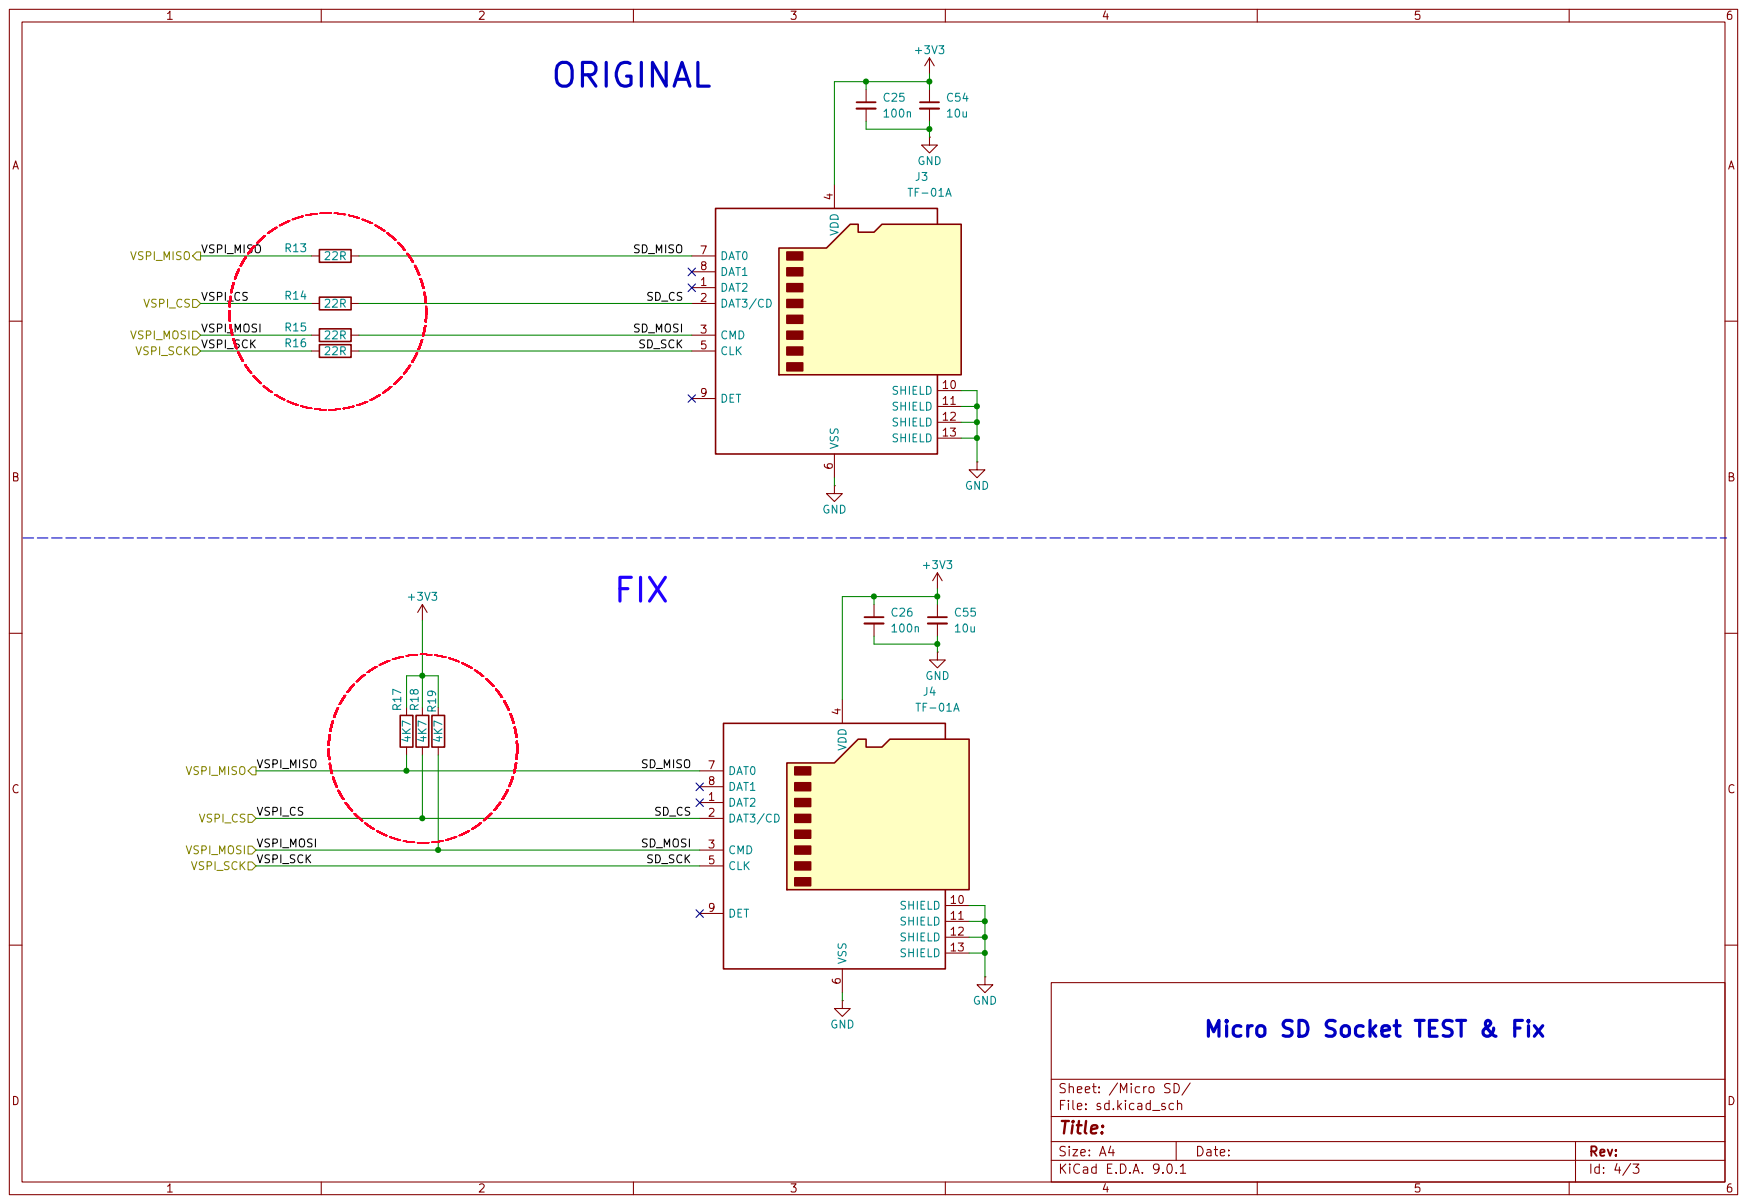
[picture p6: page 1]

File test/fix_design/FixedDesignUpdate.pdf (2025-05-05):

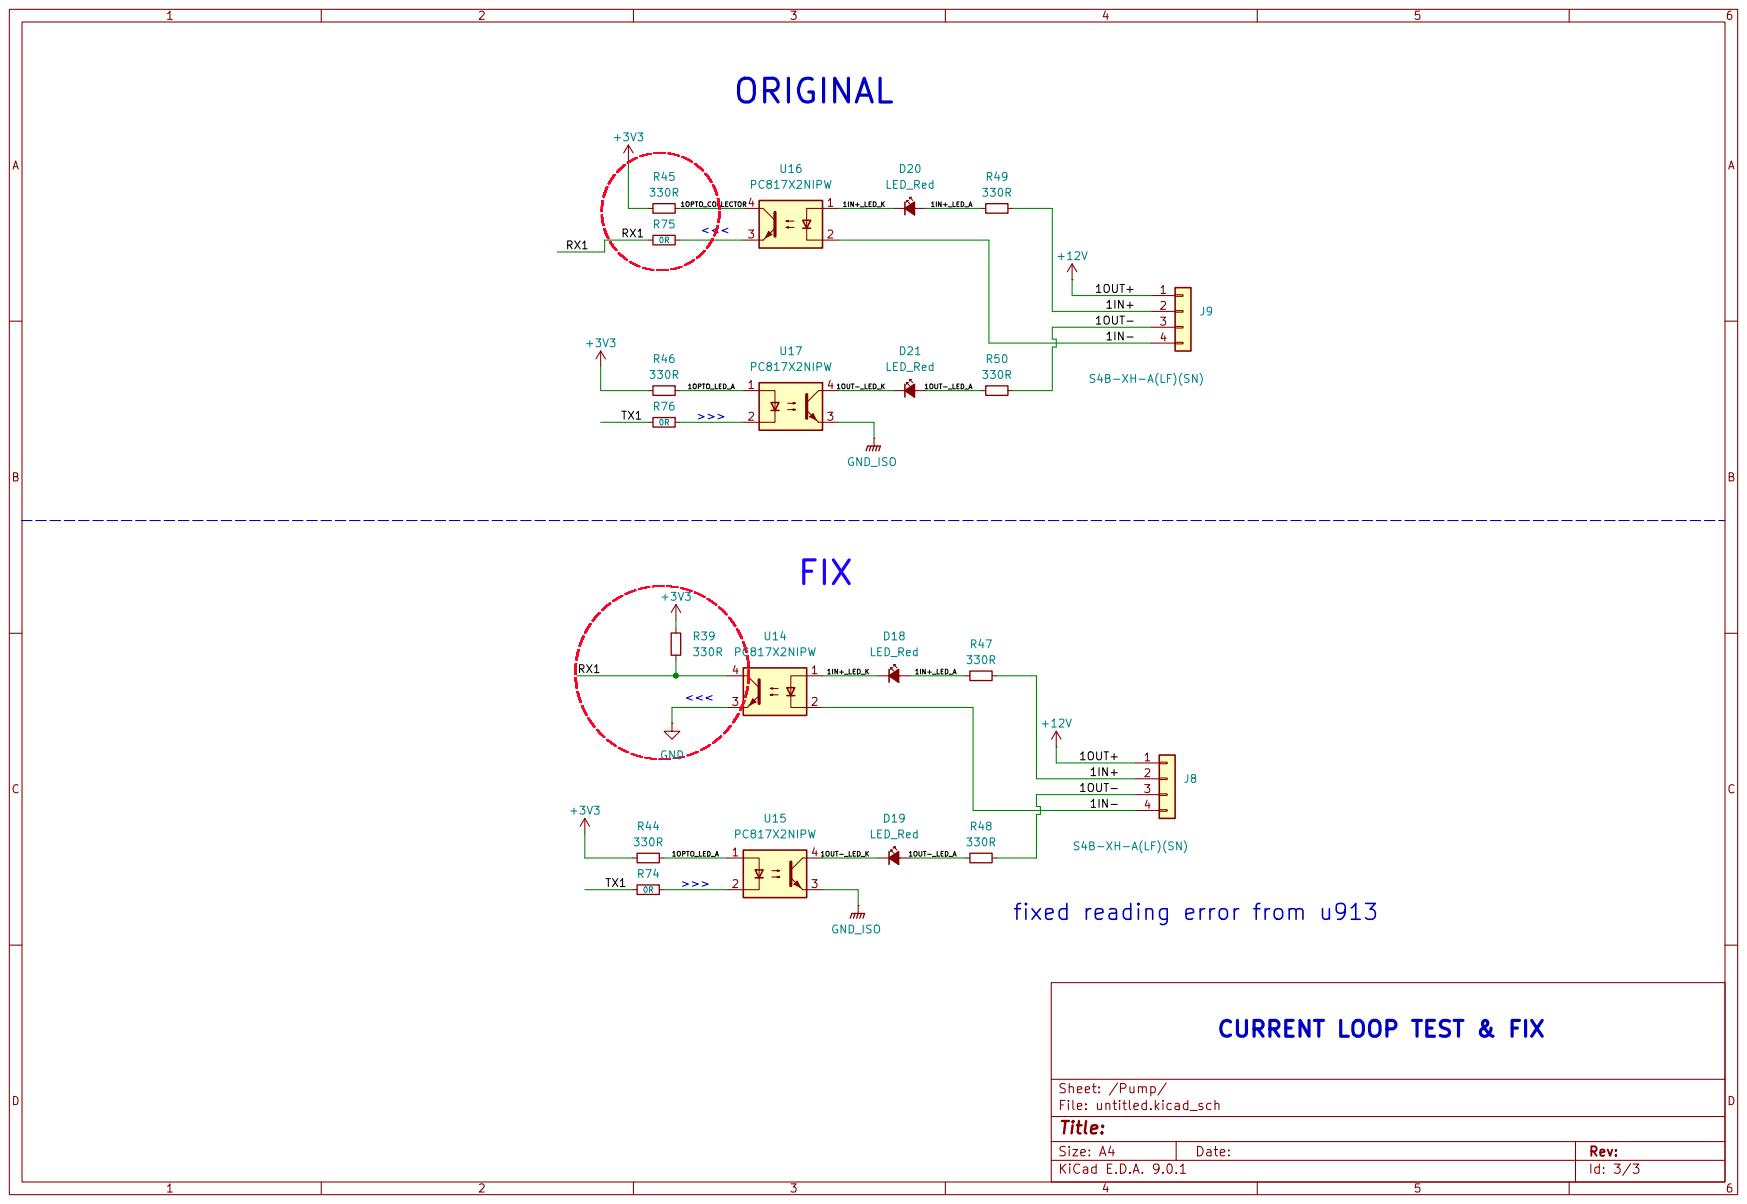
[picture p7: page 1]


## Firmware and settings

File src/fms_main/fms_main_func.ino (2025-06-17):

/*
    * fms_main_func.ino
    * This file is part of the ESP32 FMS 
    * main function link file
*/

void fms_boot_count(bool bootsave) {
  if (!bootsave) {
    return;
  }

  if (!fms_nvs_storage.begin("fms_config", false)) {
    FMS_LOG_ERROR("[fms_main_func.ino:13] Failed to initialize NVS storage");
    return;
  }
  sysCfg.bootcount = fms_nvs_storage.getUInt("bootcount", 0) + 1;
  app_cpu = xPortGetCoreID();
  FMS_LOG_INFO("[fms_main_func.ino:19] CPU %d: Boot count: %lu", app_cpu, sysCfg.bootcount);
  fms_nvs_storage.putUInt("bootcount", sysCfg.bootcount);
  fms_nvs_storage.end();  // Close NVS storage
}

void log_chip_info() {
#if SHOW_FMS_CHIP_INFO_LOG
  fms_chip_info_log();
  fms_memory_info_log();
#endif
}

bool fms_initialize_uart2() {
  if (fms_uart2_begin(use_serial1, 9600)) {
    //fms_uart2_serial.onReceive(fm_rx_irq_interrupt);  // uart interrupt function
    FMS_LOG_INFO("[FMSUART2] UART2.. DONE");
    return true;
  } else {
    FMS_LOG_ERROR("[FMSUART2] UART2.. FAIL");
    return false;
  }
}

bool fms_initialize_wifi() {
  if (initialize_fms_wifi(wifi_start_event)) {
    FMS_LOG_INFO("[fms_main_func:45] Connected to WiFi, IP: %s", WiFi.localIP().toString().c_str());
    return true;
  } else {
    FMS_LOG_WARNING("[fms_main_func:48] Failed to connect to WiFi");
    return false;
  }
}

void fms_run_sd_test() {
#if true
  fms_config_load_sd_test();
  if (!LittleFS.begin(true)) {  // preference storage (1MB)
    Serial.println("[fms_main_func.ino:57] [STORAGE] Failed to mount file system");
  } else {
    Serial.println("[fms_main_func.ino:59] [STORAGE] File system mounted");
  }
  // load system config file
#endif
}

void log_debug_info() {
#if SHOW_DEBUG_FMS_CHIP_INFO_LOG
  fms_print_after_setup_info();
  fms_log_task_list();
#endif
}

void fms_pin_mode(int pin, int mode) { // pin out declare
  pinMode(pin, mode);
}

void fms_dns_responder_init() {
  // Set up mDNS responder
  if (!MDNS.begin(deviceName)) {
    FMS_LOG_ERROR("Error setting up MDNS responder!");
  } else {
    FMS_LOG_INFO("mDNS responder started");
    // Add service to MDNS
    MDNS.addService("esp-ota", "tcp", 80);
    MDNS.addService("http", "tcp", 80);  // Add standard HTTP service for better discovery
  }
}

// format priceperliter/LSellLiter/SellLiter*PricePreLiter/Totalizer/TotalizerAmount
// generate Final Data format 
String fms_generateFinalData(int pump_id,float sell_price_liters,float sell_liters,float price,float totalizer,unsigned long long totalizer_amount){
  char buffer[100];
  snprintf(buffer, sizeof(buffer), "%02dS%.3fL%.3fP%.2fT%.3fA%llu",
           pump_id, sell_price_liters, sell_liters, price, totalizer, totalizer_amount);
  return String(buffer);
}

// generate live data format
String fms_generateLiveData(int pump_id,float price_liters,float live_liters){
  float liveLiterPrice = price_liters * live_liters;  // S = P × L
  char buffer[50];                                // Buffer to store formatted string
  // Format: "01S1097L18.232P20000"
  snprintf(buffer, sizeof(buffer), "%02dP%.2fL%.3f",
           pump_id, price_liters, live_liters);
  return String(buffer);
}

// decode preset amount from server
int fms_decodePresetAmount(String presetData){
  int p_index = presetData.indexOf('P');
  if(p_index == -1 || p_index + 1 >= presetData.length()){
    return -1; // Invalid format
  }
  String amountStr = presetData.substring(p_index + 1);
  return amountStr.toInt(); // Convert to integer
}

// decode pump id from server
int fms_decodePumpId(String presetData){
  return presetData.substring(0,2).toInt();
}

/*
{
  "device": "U8990",
  "payload": "N01L18.90P2000",
  "crc_hex": "A1B2",
  "crc_dec": 41394
}
*/

void init_staus_leds() {
    gpio_config_t io_conf = {
        .pin_bit_mask = (1ULL << LED_RED) | (1ULL << LED_GREEN) |
                        (1ULL << LED_BLUE) | (1ULL << LED_YELLOW),
        .mode = GPIO_MODE_OUTPUT,
        .pull_up_en = GPIO_PULLUP_DISABLE,
        .pull_down_en = GPIO_PULLDOWN_DISABLE,
        .intr_type = GPIO_INTR_DISABLE
    };
    gpio_config(&io_conf);
    gpio_set_level(LED_RED, 1);
    gpio_set_level(LED_GREEN, 1);
    gpio_set_level(LED_BLUE, 1);
    gpio_set_level(LED_YELLOW, 1);
}

 void fms_load_protocol_config() {

  if (!fms_nvs_storage.begin("fms_d_config", false)) {
    FMS_LOG_ERROR("[Protocol Config] Failed to initialize NVS storage");
    return;
  }

  // Load protocol type
  sysCfg.protocol = fms_nvs_storage.getString("protocol", "0");  // Default to "redstar"
  FMS_LOG_INFO("[Protocol Config] Protocol: %s", sysCfg.protocol.c_str());
  // Set protocol defines
  if (sysCfg.protocol == "redstar") {
    #define USE_REDSTAR
    #undef USE_TATSUNO
    FMS_LOG_INFO("[Protocol Config] Using Redstar protocol");
  } else if (sysCfg.protocol == "tatsuno") {
    #define USE_TATSUNO
    #undef USE_REDSTAR
    FMS_LOG_INFO("[Protocol Config] Using Tatsuno protocol");
  } else {
    FMS_LOG_ERROR("[Protocol Config] Unknown protocol, defaulting to Redstar");
    sysCfg.protocol = "0";
  }

  fms_nvs_storage.end();
}

void fms_set_protocol_config(DisConfig& cfg) {
  if (!fms_nvs_storage.begin("fms_d_config", false)) {
    FMS_LOG_ERROR("[Protocol Config] Failed to initialize NVS storage");
    return;
  }

  // Save configuration to NVS storage
  bool success = true;
  success &= fms_nvs_storage.putString("protocol", cfg.pt);
  success &= fms_nvs_storage.putUChar("devn", cfg.devn);
  success &= fms_nvs_storage.putUChar("noz", cfg.noz);

  // Save pump IDs
  char key[12];
  for (int i = 0; i < 8; i++) {
    snprintf(key, sizeof(key), "pumpid%d", i + 1);
    success &= fms_nvs_storage.putUChar(key, cfg.pumpids[i]);
  }

  if (success) {
    FMS_LOG_INFO("[Protocol Config] %s configuration saved successfully", cfg.pt.c_str());
    Serial.printf(
      "Protocol: %s, Device ID: %d, Nozzle count: %d\n"
      "Pump IDs: %d %d %d %d %d %d %d %d\n",
      cfg.pt.c_str(), cfg.devn, cfg.noz,
      cfg.pumpids[0], cfg.pumpids[1], cfg.pumpids[2], cfg.pumpids[3],
      cfg.pumpids[4], cfg.pumpids[5], cfg.pumpids[6], cfg.pumpids[7]
    );
    
    // Update system configuration
    sysCfg.protocol = cfg.pt;
  } else {
    FMS_LOG_ERROR("[Protocol Config] Failed to save some configuration values");
  }
  fms_nvs_storage.end();
}

void fms_load_config() {
  if (!fms_nvs_storage.begin("fms_config", false)) {
    FMS_LOG_ERROR("[fms_main_func:205] Failed to initialize NVS storage");
    return;
  }
  deviceName = fms_nvs_storage.getString("uuid", "ultm_25505v01_");
  FMS_LOG_INFO("[fms_main_func:209] Device UUID: %s", deviceName.c_str());
}

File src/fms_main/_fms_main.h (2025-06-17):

#ifndef _FMS_MAIN_H_
#define _FMS_MAIN_H_
#include <WebServer.h>
#include <ArduinoJson.h>
#include <WiFi.h>
#include "time.h"
#include <LittleFS.h>
#include "chip-debug-report.h"
#include "esp32-hal-uart.h"
#include <Preferences.h>
#include <nvs.h>
#include <nvs_flash.h>
#include "Ticker.h"
#include <math.h>
#include <HTTPClient.h>
#include <HTTPUpdate.h>
#include <WebSocketsServer.h>
#include <PubSubClient.h>
// protocol
#include <ModbusMaster.h>
// sd config
#include <SD.h>
#include <FS.h>
#include <SPI.h>
// ota server
#include <ESPmDNS.h>
#include <WebServer.h>
#include <Update.h>

#include <esp_task_wdt.h>
#include <esp_ota_ops.h> 
#include <EEPROM.h>

#include <MFRC522.h>

Ticker ticker;

#define BUILTIN_LED                     2  
// Device details
#define STATION_ID                      1                     // station id
#define SHOW_DEBUG_SYS_LOG              true
#define SHOW_DEBUG_SD_TEST_LOG          true
#define SHOW_DEBUG_FMS_CHIP_INFO_LOG    false
#define SHOW_UART_SYS_LOG               true                  // show uart log
#define SHOW_RESP_UART_SYS_LOG          true

// WiFi configuration
#define WIFI_SSID sysCfg.wifi_ssid              // wifi ssid
#define WIFI_PASSWORD sysCfg.wifi_password      // wifi password
#define MQTT_SERVER sysCfg.mqtt_server_host     // mqtt server address
#define MQTT_PORT 1883                          // mqtt port
#define MQTT_USER "detpos"                      // mqtt user
#define MQTT_PASSWORD "asdffdsa"                // mqtt password

#define MQTT_LWT_OFFLINE "offline"              // mqtt last will topic offline
#define MQTT_LWT_ONLINE "online"                // mqtt last will topic online
#define mqttTask true
#define WEB_SERVER_PORT 80                          // web server port

// SD configuration 
#define SD_CARD_CS_PIN 5                            // sd card chip select pin
#define SD_CARD_CONFIG_FILE_NAME "fms_config.txt"   // sd card file name change it to your file name

// Time configuration
#define NTP_SERVER "pool.ntp.org"                   // ntp server
#define GMT_OFFSET_SEC (7 * 3600)                   // gmt offset in seconds to fix time zone
#define DAYLIGHT_OFFSET_SEC 0                       // daylight offset in seconds to fix time zone
#define _log_printf log_printf                      // in build in chip-debug-report.cpp
#define fms_cli_serial Serial                       // cli serial port
#define fms_uart2_serial Serial1                    // uart2 serial port

#define LED_BUILTIN                 2
#define chip_report_printf          log_printf  
// lanfeng modbus
#define MAX485_DE 15
#define MAX485_RE_NEG 15
ModbusMaster node;
#define PUMP_REQUEST_TIMEOUT_MS     10000             // 10 seconds timeout for pump request  

// multiplexer
// additional information datasheet : https://www.lcsc.com/datasheet/lcsc_datasheet_2004021806_HGSEMI-74HC4052M-TR_C507179.pdf
#define USE_MUX_PC817    // using  Multiplexers (74hc4052m)
//#define DISABLE_PC817
#ifdef DISABLE_MUX_PC817 /// pc817 close
  #undef USE_MUX_PC817
#endif
#define MUX_S0                      25
#define MUX_S1                      26
#define MUX_E                       27 // enable input (active LOW) 
// uart 2 config
#define RXD2                        16
#define TXD2                        17
// led status config
#define LED_RED                     GPIO_NUM_32
#define LED_GREEN                   GPIO_NUM_14 
#define LED_BLUE                    GPIO_NUM_13
#define LED_YELLOW                  GPIO_NUM_33
// uartReceive state
bool UART_RECEIVE_STATE             = true;
// nozzle config
#define MAX_NOZZLES                 2 // change your noz count
bool pump_approve[MAX_NOZZLES]      = {false};

/* OTA  configuration  parameter */
bool          otaInProgress         = false;
uint8_t       otaProgress           = 0;
const char*   updateStatus          = "Idle";
size_t        contentLength         = 0;
size_t        uploadedBytes         = 0;
unsigned long uptime                = 0;
unsigned long lastUptimeUpdate      = 0;
unsigned long lastInfoRequest       = 0;
String cachedInfoResponse           = "";
const unsigned long INFO_CACHE_TIME = 1000;     // 1 second cache
bool isAuthenticated                = false;    // optional ota password
/* end ota configuration parameter */
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

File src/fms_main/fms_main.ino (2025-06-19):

/*
  FMS main source file
  Author: Trion
  Date: 2025
  Guided By Senior Engineer : Sir Thiha Kyaw
  Description: This file is the main source file of FMS project.
*/
 

/* device login page */
const String correctUsername = "admin";           /* change your login username here*/
const String correctPassword = "admin";           /* change your login pass here*/
const String firmwareVersion = "2.0.0";           /* Current firmware version*/
String deviceName            = "ultm_25505v01_";  /* device ID (for)  change here like this user can change with configpanel*/
#define CLI_PASSWORD         "admin"              /* cli password change this password*/
/* end change note  */


#include "_fms_main.h"
#include "src/_fms_cli.h"
#include "src/_fms_debug.h"
#include "src/_fms_json_helper.h"
#include "src/_fms_lanfeng.h"
#include <src/_fms_redstar.h>           /* test features */
#include <src/_fms_tatsuno.h>
#include <src/_fms_filemanager.h>        /* test features */
#include <src/_fms_touch.h>

 #define USE_TOUCH
// #define FMS_TATSUNO_DEBUG_OPEN
// #define USE_V2_OTA_SERVER
// #define USE_RESTAR 
// #define USE_TATSUNO
// #define USE_REDSTAR
// #define USE_TOUCH
// #define DISABLE_MQTT_DEBUG
// #ifdef DISABLE_MQTT_DEBUGP
// #undef FMS_MQTT_DEBUG
// #endif
// #define USE_MQTT_DEBUG
// #define  USE_LANFENG        // Undefine USE_LANFENG to disable the library

#define USE_CLI
//#define USE_TATSUNO
#define DISABLE_LANFENG
#ifdef DISABLE_LANFENG
#undef USE_LANFENG
#endif

FMS_FileManager fileManager;
fms_cli fms_cli(fms_cli_serial, CLI_PASSWORD);      // Use "admin" as the default password change your admin pass here
Redstar redstar(fms_uart2_serial);                  // create redstar object
TatsunoProtocol tatsuno(fms_uart2_serial);          // Create an instance of TatsunoProtocol with the HardwareSerial object
fmsLanfeng lanfeng(22, 22);                         // set re de pin (DTR PIN)s

/* Main function */

void setup() {

  init_staus_leds();                         // initialize status LEDs
  gpio_set_level(LED_RED, LOW);              // turn on red led

#ifdef USE_CLI
  fms_cli.begin(115200);  // Initialize the CLI with a baud rate of 115200
  fms_cli.register_command("wifi",         "Configure WiFi settings",       handle_wifi_command, 2, 2);
  fms_cli.register_command("wifi_connect", "Connect to WiFi network",       handle_wifi_connect_command, 2, 2);
  fms_cli.register_command("restart",      "Restart the system",            handle_restart_command);
  fms_cli.register_command("wifiscan_safe", "Scan for WiFi networks (safe mode)", handle_wifi_scan_safe_command);
  fms_cli.register_command("wifiread",      "Read current WiFi status",     handle_wifi_read_command);
  fms_cli.register_command("wifi_test",     "Test WiFi connection",         handle_wifi_test_command);
  fms_cli.register_command("uuid_change",   "Change Your Device Id unique address", handle_device_id_change_command, 1, 1);
  fms_cli.register_command("protocol",      "Set Protocol",                 handle_protocol_command, 1, 1);
  fms_cli.register_command("protocol_config","Set Protocol Config",       handle_protocol_config_command, 11, 11);
  fms_cli.register_command("mqtt_config"   ,"Configure Mqtt settings",     handle_mqtt_command,2,2);
  fms_cli.register_command("noz_config", "Configure Nozzle settings",   handle_nozzle_command, 16, 16);
#endif
 
  fms_run_sd_test();                        // demo test fix this load configure data from sd card
  fmsEnableSerialLogging(true);             // show serial logging data on Serial Monitor
  fms_boot_count(true);                     // boot count
  fms_load_config();                        // load config from nvs storage
 
/* not included in v1 */
#ifdef USE_MUX_PC817
  fms_pin_mode(MUX_S0, OUTPUT);             // Multiplexer
  fms_pin_mode(MUX_S1, OUTPUT);
  fms_pin_mode(MUX_E, OUTPUT);
  enable_mux(MUX_E);                        // enable multiplexer (active low)
#endif

/* not included in v1 */
#ifdef USE_LANFENG                         // lanfeng Protocol
  FMS_LOG_INFO("[LANFENG] Starting Lanfeng");
  lanfeng.init(1, fms_uart2_serial);       // add slave id
#endif

#ifdef USE_REDSTAR
  red_star_init();                         // redstar init
#endif

#ifdef USE_TATSUNO
  fms_tatsuno_init();                      // tatsuno init
#endif

/* task create */
  if (fms_initialize_wifi()) {             // wifi is connected create all task s
    fms_task_create();
  }



  /* test features protocol selection */
  /*
  fms_load_protocol_config();  // load protocol config from nvs storage
  while (sysCfg.protocol == "0") {  // wait for protocol to be set
    FMS_LOG_ERROR("Protocol not set, waiting...");
    vTaskDelay(pdMS_TO_TICKS(1000));  // wait for 1 second
  }
  // /* test features
  // if (fms_initialize_wifi() && sysCfg.protocol != "0") {  // wifi is connected create all task s
  //   fms_task_create();
  // }
 */

}

void loop() {
}

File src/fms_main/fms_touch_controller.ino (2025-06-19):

#ifndef USE_TOUCH

void fms_touch_init() {
eeprom_init();
default_setup_all();
mqtt_topic_change();
screen_brightness_in();

}

/* old version */
void fms_touch_main_loop() {
  if (brightness_check) screen_brightness_out();
    hmi_two_main_fun();
}

void hmi_two_main_fun() {  // for hmi two main function
  Hmi_Two_setup();
  if (rfid_check_two) rfid_setup_two();
  if (rfid_auth_check_two) rfid_auth_two();
}

void Hmi_Two_setup() {

  if (Serial2.available() > 0) {

    Hmi_time = millis() / 1000;  // for brightness time

    for (int i = 0; i < 40; i++) {
      Hmi_Buffer[i] = Serial2.read();
      delay(2);
      // Serial.print(Hmi_Buffer[i], HEX);
      // Serial.print(" ");
    }
    // Serial.println();

    if (Hmi_Buffer[4] == 0x12) {
      rfid_card_check_two = false;

      switch (Hmi_Buffer[8]) {
        case 0x01:
          buzzer_song_two();
          common_pump_Id_two = pumpid1;
          dispenser_ID_two = 1;
          break;

        case 0x02:
          buzzer_song_two();
          common_pump_Id_two = pumpid2;
          dispenser_ID_two = 2;
          break;

        case 0x03:
          buzzer_song_two();
          common_pump_Id_two = pumpid3;
          dispenser_ID_two = 3;

          break;
        case 0x04:
          buzzer_song_two();
          common_pump_Id_two = pumpid4;
          dispenser_ID_two = 4;
          break;

        case 0x05:
          buzzer_song_two();
          common_pump_Id_two = pumpid5;
          dispenser_ID_two = 5;
          break;

        case 0x06:
          buzzer_song_two();
          common_pump_Id_two = pumpid6;
          dispenser_ID_two = 6;
          break;

        case 0x07:
          buzzer_song_two();
          common_pump_Id_two = pumpid7;
          dispenser_ID_two = 7;
          break;

        case 0x08:
          buzzer_song_two();
          common_pump_Id_two = pumpid8;
          dispenser_ID_two = 8;
          break;
      }

      if (casher_lock_check == 1) {
        master_http_login_post_two(master_rfid);

        if (master_check) {
          vehicle_setup_two();
          master_check = false;

        } else {
          Page_change[9] = 0x05;
          Serial2.write(Page_change, 10);
          Serial2.write(Page_change, 10);
        }

      } else rfid_check_two = true;

    } else if (Hmi_Buffer[4] == 0x23 && Hmi_Buffer[5] == 0x00) {  // to read car no
      // Serial.println(" read car no");
      for (int j = 0; j < 15; j++) Car_no_two[j] = 0;

      for (int i = 0; i < 15; i++) {
        if (Hmi_Buffer[7 + i] == 0xff) break;
        Car_no_two[i] = Hmi_Buffer[7 + i];
        delay(1);
      }
      Serial.print("Hmi two Car number is => ");
      Serial.println(Car_no_two);

    } else if (Hmi_Buffer[4] == 0x24 && Hmi_Buffer[5] == 0x00) {  // to read member id
      for (int j = 0; j < 20; j++) Member_id_two[j] = 0;

      for (int i = 0; i < 15; i++) {
        if (Hmi_Buffer[7 + i] == 0xff) break;
        Member_id_two[i] = Hmi_Buffer[7 + i];
        delay(1);
      }
      Serial.print("Hmi two Member id is => ");
      Serial.println(Member_id_two);

    } else if (Hmi_Buffer[4] == 0x25 && Hmi_Buffer[5] == 0x00) {  // to read member name
      for (int j = 0; j < 20; j++) Member_name_two[j] = 0;

      for (int i = 0; i < 15; i++) {
        if (Hmi_Buffer[7 + i] == 0xff) break;
        Member_name_two[i] = Hmi_Buffer[7 + i];
        delay(1);
      }
      Serial.print("Hmi two Member name is => ");
      Serial.println(Member_name_two);

    } else if (Hmi_Buffer[4] == 0x22 && Hmi_Buffer[5] == 0x00) {  // to read vehicle type
      for (int j = 0; j < 4; j++) vehicle_type_two[j] = 0;

      for (int i = 0; i < 4; i++) {
        if (Hmi_Buffer[8 + i] == 0xff) break;
        vehicle_type_two[i] = Hmi_Buffer[8 + i];
      }
      // Serial.println(vehicle_type_two);
      vehicle_value_two = vehicle_type_two[0] + 1;
      Serial.print("Hmi two vehicle type is => ");
      Serial.println(vehicle_value_two);

      // vehicle_type_name_two(vehicle_value_two);  // to setup vehicle name

    } else if (Hmi_Buffer[4] == 0x21 && Hmi_Buffer[5] == 0x00) {  // to read cash type id
      for (int j = 0; j < 4; j++) cash_type_two[j] = 0;

      for (int i = 0; i < 4; i++) {
        if (Hmi_Buffer[8 + i] == 0xff) break;
        cash_type_two[i] = Hmi_Buffer[8 + i];
      }

      cash_value_two = cash_type_two[0] + 1;
      Serial.print("Hmi two Cash type id => ");
      Serial.println(cash_value_two);

    } else if (Hmi_Buffer[4] == 0x32 && Hmi_Buffer[5] == 0x00) {  // for liter calculation and read liter
      Serial.println(" liter count in hmi two");

      Total_check_two = false;
      over_all_li_price_check_two = true;
      liter_check_two = true;
      price_check_two = false;
      preset_check_two = false;

      for (int j = 0; j < 10; j++) Liter_count_two[j] = 0;

      for (int i = 0; i < 10; i++) {
        if (Hmi_Buffer[9 + i] == 0xff) break;
        Liter_count_two[i] = Hmi_Buffer[9 + i];
        Serial.print(Liter_count_two[i], HEX);
        Serial.print(" ");
      }
      Serial.println();

      combine_Liter_two = (Liter_count_two[0] << 8) | Liter_count_two[1];
      Serial.print("Hmi two Liter count is => ");
      Serial.println(combine_Liter_two);

      liter_calculation_check_two(combine_Liter_two);  // for calculation

    } else if (Hmi_Buffer[4] == 0x33 && Hmi_Buffer[5] == 0x00) {  // to read price data

      over_all_li_price_check_two = true;
      liter_check_two = false;
      price_check_two = true;
      Total_check_two = false;
      preset_check_two = false;

      for (int j = 0; j < 5; j++) Price_count_two[j] = 0;

      for (int i = 0; i < 5; i++) {
        if (Hmi_Buffer[8 + i] == 0xff) break;
        Price_count_two[i] = Hmi_Buffer[8 + i];
        Serial.print(Price_count_two[i], HEX);
        Serial.print(" ");
      }
      Serial.println();

      combine_price_two = (Price_count_two[0] << 16) | (Price_count_two[1] << 8) | Price_count_two[2];
      Serial.print("Hmi two price count is => ");
      Serial.println(combine_price_two);

      price_calculation_check_two(combine_price_two);

    } else if (Hmi_Buffer[4] == 0x4A && Hmi_Buffer[5] == 0x11) {  // to read F1 liter value
      // Serial.println("f1 read liter in hmi two");
      F1_liter_check_two = true;
      F1_price_check_two = false;
      for (int j = 0; j < 5; j++) F1_liter_two[j] = 0;

      for (int i = 0; i < 8; i++) {
        if (Hmi_Buffer[9 + i] == 0xff) break;
        F1_liter_two[i] = Hmi_Buffer[9 + i];
      }
      // Serial.println();

      F1_liter_value_two = (F1_liter_two[0] << 8) | F1_liter_two[1];
      Serial.print("Hmi two F1 liter value is => ");
      Serial.println(F1_liter_value_two);

      Default_preset_price[4] = 0x4A;
      Default_preset_price[5] = 0x21;

      Serial2.write(Default_preset_price, 10);
      Serial2.write(Default_preset_price, 10);
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

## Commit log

2025-02-03 add log print
2025-02-03 add uart
2025-02-04 fix printf
2025-02-06 remove samephore of uart1
2025-02-06 change to fix uart to serial arduino api interrupt
    [fms_main.ino, fms_uart2.ino, fms_wifi.ino]
2025-02-26 change serial interrupt to onReceive interrupt
2025-02-28 fix interrupt
2025-03-04 add uart2 485
2025-03-14 fix log print

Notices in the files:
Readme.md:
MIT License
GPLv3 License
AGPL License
